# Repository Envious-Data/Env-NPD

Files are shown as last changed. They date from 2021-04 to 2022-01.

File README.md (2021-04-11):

# Env-NPD
A Raspberry Pi Pico powered Numpad!
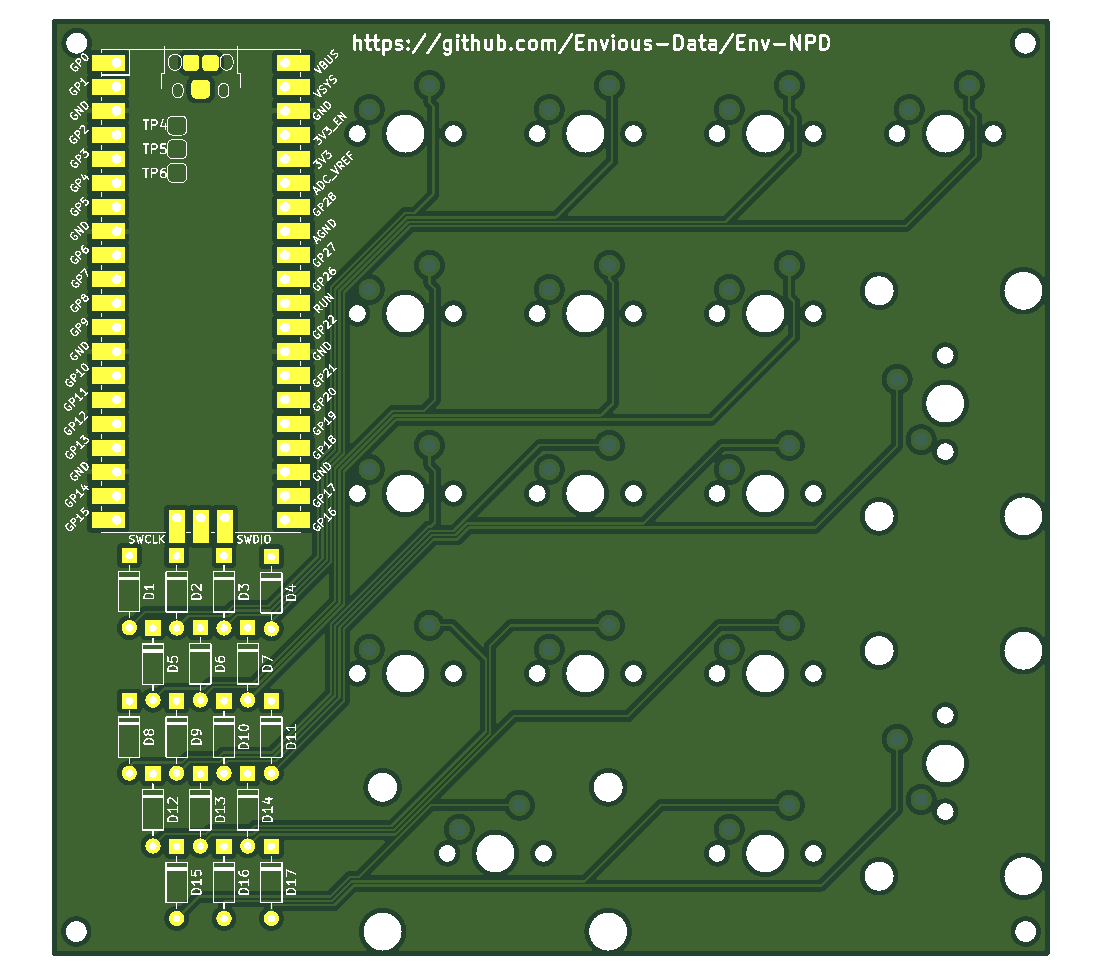
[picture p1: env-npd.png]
Board Image


### What is this?
This is another RPI Pico type mechanical board thing alike my other project but a entirely seperate numpad!

This will use KMK and CircuitPython and should be incredibly easy to build.

### Parts List
* 1x Raspberry Pi Pico
* 17x Keyboard Switches of your choosing
* 17x 1N4148 Diodes (through hole)
* Numpad Keycap set
* Numpad PCB

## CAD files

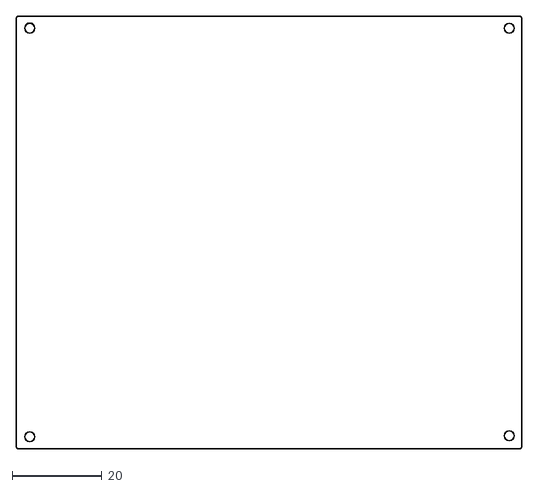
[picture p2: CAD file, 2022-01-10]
_gerber/Bottom Case.dxf
112.4 x 96.0

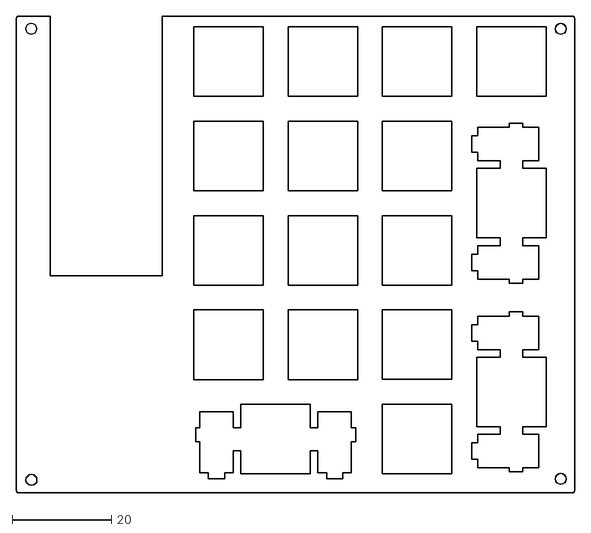
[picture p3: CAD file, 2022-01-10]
_gerber/Top Plate.dxf
112.4 x 96.0

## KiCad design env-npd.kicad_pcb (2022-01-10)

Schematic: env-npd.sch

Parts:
D1, D2, D3, D4, D5, D6, D7, D8, D9, D10, D11, D12, D13, D14, D15, D16, D17: D_Small; D_DO-35_SOD27_P7.62mm_Horizontal
H1, H2, H3, H4: MountingHole; MountingHole_2.2mm_M2
MCU1: Pico; Rpi-pico-modified
MX1, MX2, MX3, MX4, MX5, MX6, MX7, MX8, MX9, MX10, MX12, MX13, MX14, MX16: MX-NoLED; MXOnly-1U-NoLED
MX11, MX15, MX17: MX-NoLED; MXOnly-2U-NoLED

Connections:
GND: MCU1.3 (GND), MCU1.8 (GND), MCU1.13 (GND), MCU1.18 (GND), MCU1.23 (GND), MCU1.28 (GND), MCU1.33 (AGND), MCU1.38 (GND)
unnamed: D1.2 (A), MX1.2 (ROW)
unnamed: D2.2 (A), MX2.2 (ROW)
unnamed: D3.2 (A), MX3.2 (ROW)
unnamed: D4.2 (A), MX4.2 (ROW)
unnamed: D5.2 (A), MX5.2 (ROW)
unnamed: D6.2 (A), MX6.2 (ROW)
unnamed: D7.2 (A), MX7.2 (ROW)
unnamed: D8.2 (A), MX8.2 (ROW)
unnamed: D9.2 (A), MX9.2 (ROW)
unnamed: D10.2 (A), MX10.2 (ROW)
unnamed: D11.2 (A), MX11.2 (ROW)
unnamed: D12.2 (A), MX12.2 (ROW)
unnamed: D13.2 (A), MX13.2 (ROW)
unnamed: D14.2 (A), MX14.2 (ROW)
unnamed: D15.2 (A), MX15.2 (ROW)
unnamed: D16.2 (A), MX16.2 (ROW)
unnamed: D17.2 (A), MX17.2 (ROW)
col0: MCU1.34 (GPIO28_ADC2), MX1.1 (COL), MX5.1 (COL), MX8.1 (COL), MX12.1 (COL)
col1: MCU1.32 (GPIO27_ADC1), MX2.1 (COL), MX6.1 (COL), MX9.1 (COL), MX13.1 (COL), MX15.1 (COL)
col2: MCU1.31 (GPIO26_ADC0), MX3.1 (COL), MX7.1 (COL), MX10.1 (COL), MX14.1 (COL), MX16.1 (COL)
col3: MCU1.29 (GPIO22), MX4.1 (COL), MX11.1 (COL), MX17.1 (COL)
row0: D1.1 (K), D2.1 (K), D3.1 (K), D4.1 (K), MCU1.27 (GPIO21)
row1: D5.1 (K), D6.1 (K), D7.1 (K), MCU1.26 (GPIO20)
row2: D8.1 (K), D9.1 (K), D10.1 (K), D11.1 (K), MCU1.25 (GPIO19)
row3: D12.1 (K), D13.1 (K), D14.1 (K), MCU1.24 (GPIO18)
row4: D15.1 (K), D16.1 (K), D17.1 (K), MCU1.22 (GPIO17)

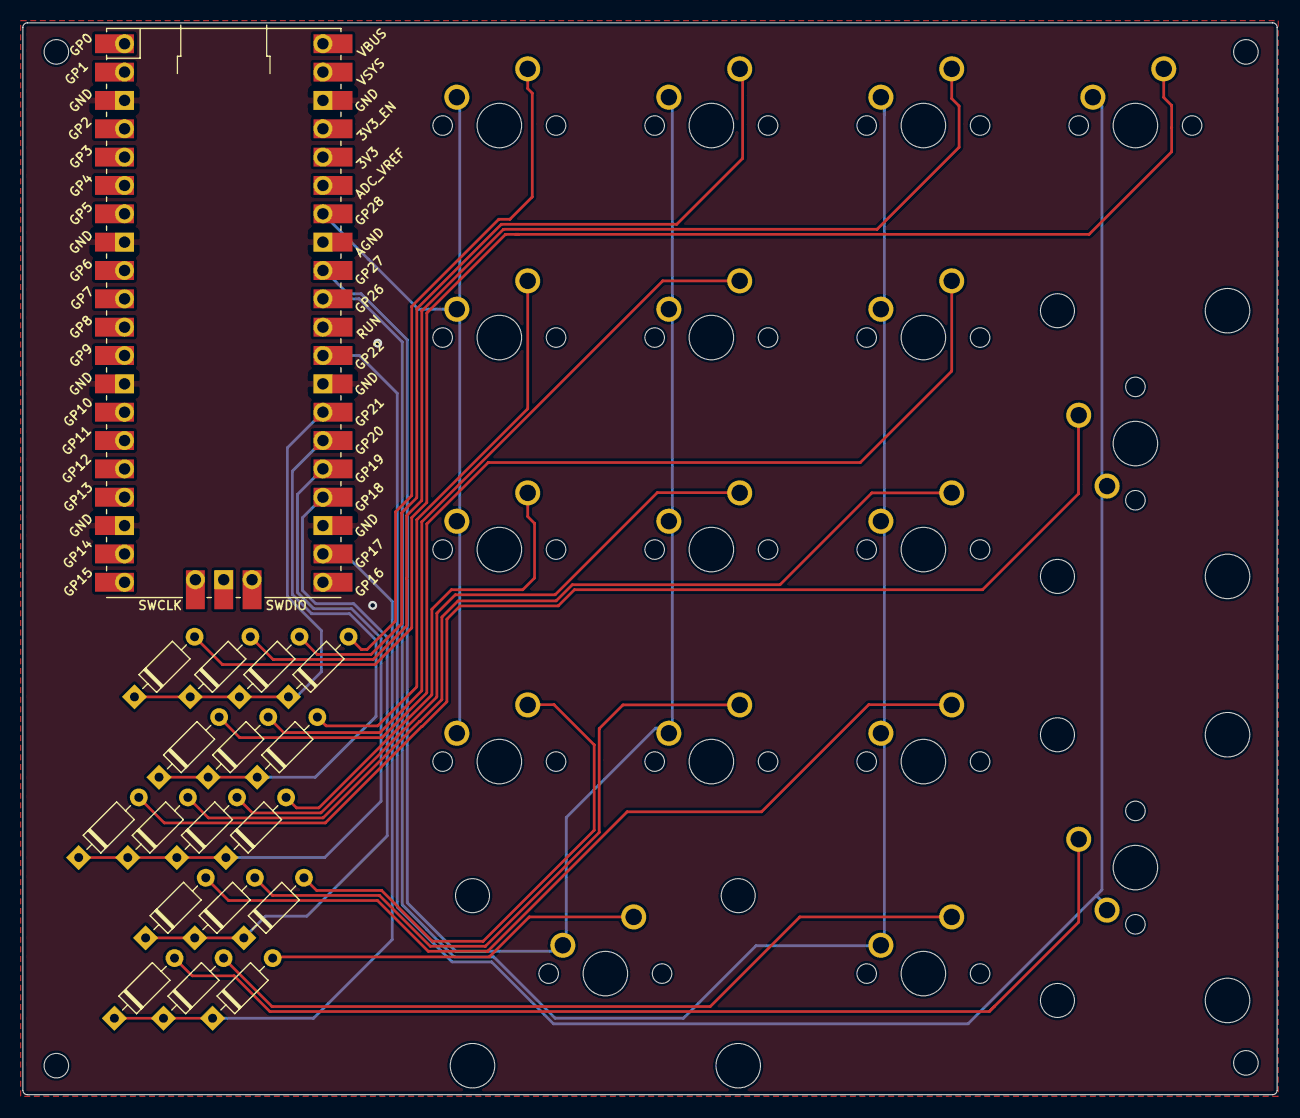
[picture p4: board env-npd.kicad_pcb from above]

Board: 2 copper layers, 112.4 x 96.0 mm, 39 parts (0 on the bottom side), 27 nets.

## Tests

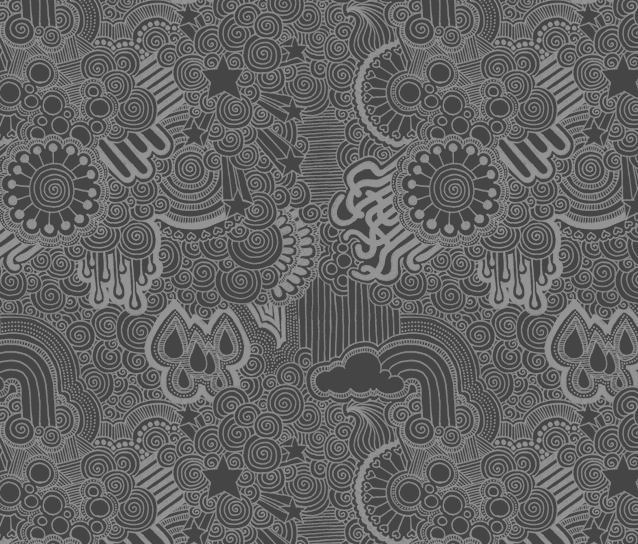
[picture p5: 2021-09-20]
_misc/gfx patern test.png

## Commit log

2021-04-11 Initial commit +1
    [env-npd.kicad_pcb, env-npd.sch]
2021-04-11 Small changes, updated readme
    [env-npd.kicad_pcb]
2021-04-11 Beginnings of an acrylic sandwich case
    [env-npd.kicad_pcb]
2021-04-11 adjusted size and removed TP pads
    TP pads aren't needed and they are way too close together, they may cause issues with a PCB manufacturer whos tolerances are looser than JLCPCBs
    [env-npd.kicad_pcb, env-npd.sch]
2021-04-11 Added lines for plate design.
    [env-npd.kicad_pcb]
2021-09-20 I couldn't sleep so I re-designed the pcb a bit and may actually order some for my self (since I need me a numpad)
    [env-npd.kicad_pcb, env-npd.sch]
2021-09-20 added a silkscreen design and generated gerbers
    [env-npd-B_Cu.gbl, env-npd-B_Mask.gbs, env-npd-B_Paste.gbp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]
2022-01-10 updated design, added outlines for a basic case on Eco1.user and Eco2.user
2022-01-10 Generated Updated gerber and exported DXFs for top and bottom plate.
    [Bottom Case.dxf, Top Plate.dxf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]
2022-01-10 couple more update bits
    [env-npd.kicad_pcb]
